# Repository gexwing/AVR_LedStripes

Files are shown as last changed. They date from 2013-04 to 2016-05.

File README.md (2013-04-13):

AVR_LedStripes
==============

Overview
-------
This Project uses an Atmega8 microcontroller to control RGB Led Stripes. The goal of this project is to have a nice modular platform with various modules to control the Color via IR Remote, Sound, or maybe other methods in the future.

src/ - The sourcecode for the Atmege, written in C.  
docs/ - documentation for hardware parts and application notes.  
eagle/ - CadSoft Eagle Schematics and Board Layout Files.  
TLSpice/ - Simulation files to test parts of the board schematics.  

Modules
-------
IRMP - Infrared Multiprotocol decoder  
SoftPWM - Software Pulse-Width-Modulation with 3 Channels via Timer Interrupt

TODO
-------
[x] Bring code upto date for v2 Board  
[] investigate gamma correction for PWM Module  
[] Add a microphone with preamp to the board for sound sampling.  
[] Add a FFT Module for anazyling sound spectrums.  
[] Add Mode for Sounds Controled Lighting  

Links
-------
Using Lookup Tables for Gamma Correction on LEDs: http://www.maximintegrated.com/app-notes/index.mvp/id/3667  
Fixed-Point FFT for Atmega: http://elm-chan.org/works/akilcd/report_e.html  
Infrared-Multiprotocol-Decoder: http://www.mikrocontroller.net/articles/IRMP  

License
-------
TBA

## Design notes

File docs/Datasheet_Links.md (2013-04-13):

FDS8884 Datasheet (N-Channel MOSFET)
------
http://www.fairchildsemi.com/ds/FD/FDS8884.pdf

TSOP1736 (IR Receiver)
------
http://www.datasheetcatalog.org/datasheets/208/301092_DS.pdf

Atmega8
------
http://www.atmel.com/devices/atmega8.aspx?tab=documents
http://www.atmel.com/Images/Atmel-2486-8-bit-AVR-microcontroller-ATmega8_L_datasheet.pdf

Application Note - AVR335: Digital Sound Recorder with tinyAVR or megaAVR and DataFlash 
------
http://www.atmel.com/Images/doc1456.pdf

Article (DE): Festkommaarithmetik
------
http://www.mikrocontroller.net/articles/Festkommaarithmetik

Article (DE): Analog-Digital-Converter
------
http://www.mikrocontroller.net/articles/AVR-GCC-Tutorial/Analoge_Ein-_und_Ausgabe

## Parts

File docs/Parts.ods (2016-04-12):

Farnell | Part Description | Cost (per unit)
1712816 | EPSON QUARZ, FA-238, 16MHZ | SFr. 0.705
2443176 | ATMEL ATMEGA328-AUR | SFr. 3.590
2407172 | ATMEL ATATMEL-ICE-BASIC DEBUGGER | SFr. 53.440
1366575 | STMICROELECTRONICS L78M05ABDT-TR TO-252-3 | SFr. 0.380
1779689 | VISHAY TSOP75236TT Infrarot-Empfänger | SFr. 1.050
2472147 | NETZANSCHLUSSBUCHSE, 5A, 24VDC | SFr. 1.900
2472151 | NETZANSCHLUSSBUCHSE, 5A, 24VDC | SFr. 1.900

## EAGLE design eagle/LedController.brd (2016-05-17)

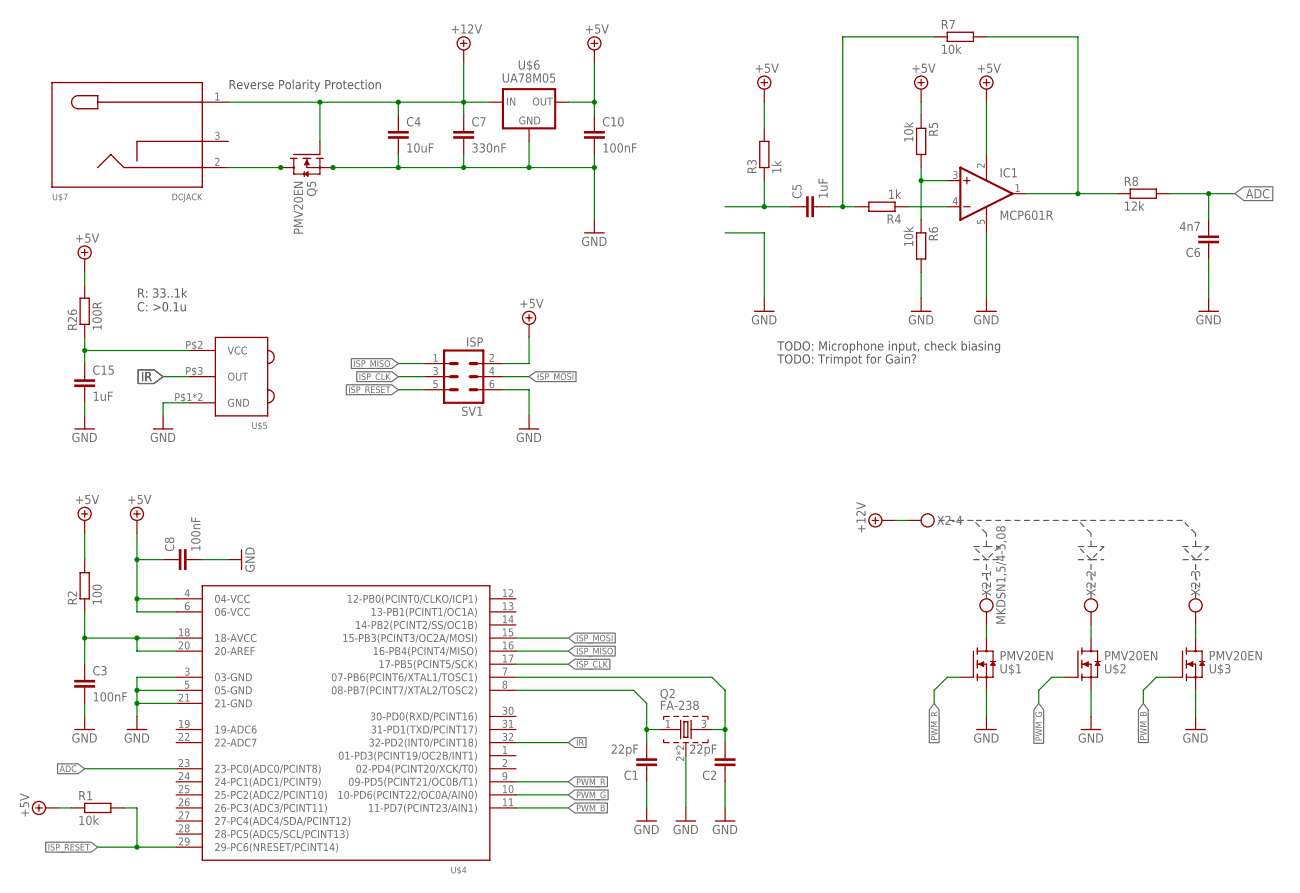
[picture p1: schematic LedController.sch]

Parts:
C1, C2: 22pF; C0805
C3, C8, C10: 100nF; C0805
C4: 10uF; C0805
C5, C15: 1uF; C0805
C6: 4n7; C0805
C7: 330nF; C0805
IC1: MCP601R; SOT23-5
Q2: FA-238
Q5: PMV20EN; SOT23
R1, R5, R6, R7: 10k; R0805
R2: 100; R0805
R3: 1k; M0805
R4: 1k; R0805
R8: 12k; R0805
R26: 100R; R0805
SV1: ISP; MA03-2
U$1, U$2, U$3: PMV20EN; SOT23
U$4: ATMEGA328; TQFP32
U$5: TSOP75236
U$6: UA78M05; SOT-223
U$7: DCJACK
X2: MKDSN1,5/4-5,08

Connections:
+5V: C8.1, C10.1, IC1.2 (V+), R1.1, R2.2, R3.2, R5.1, R26.2, SV1.2, U$4.4 (04-VCC), U$4.6 (06-VCC), U$6.3 (OUT)
+12V: C4.1, C7.1, Q5.1 (G), U$6.1 (IN), U$7.1, X2.4
ADC: C6.2, R8.2, U$4.23 (23-PC0(ADC0/PCINT8))
GND: C1.1, C2.1, C3.2, C4.2, C6.1, C7.2, C8.2, C10.2, C15.2, IC1.5 (V-), Q2.2, Q2.4 (2), Q5.2 (S), R6.2, SV1.6, U$1.2 (S), U$2.2 (S), U$3.2 (S), U$4.3 (03-GND), U$4.5 (05-GND), U$4.21 (21-GND), U$5.P$1 (GND), U$5.P$4 (GND), U$6.2 (GND), U$6.TER (GND)
IR: U$4.32 (32-PD2(INT0/PCINT18)), U$5.P$3 (OUT)
ISP_CLK: SV1.3, U$4.17 (17-PB5(PCINT5/SCK))
ISP_MISO: SV1.1, U$4.16 (16-PB4(PCINT4/MISO))
ISP_MOSI: SV1.4, U$4.15 (15-PB3(PCINT3/OC2A/MOSI))
ISP_RESET: R1.2, SV1.5, U$4.29 (29-PC6(NRESET/PCINT14))
unnamed: C5.1, R3.1
unnamed: U$1.3 (D), X2.1
unnamed: U$2.3 (D), X2.2
unnamed: U$3.3 (D), X2.3
unnamed: C3.1, R2.1, U$4.18 (18-AVCC), U$4.20 (20-AREF)
unnamed: Q5.3 (D), U$7.2
unnamed: C5.2, R4.2, R7.1
unnamed: IC1.4 (-IN), R4.1
unnamed: IC1.3 (+IN), R5.2, R6.1
unnamed: IC1.1 (OUT), R7.2, R8.1
unnamed: C1.2, Q2.1, U$4.8 (08-PB7(PCINT7/XTAL2/TOSC2))
unnamed: C2.2, Q2.3, U$4.7 (07-PB6(PCINT6/XTAL1/TOSC1))
unnamed: C15.1, R26.1, U$5.P$2 (VCC)
PWM_B: U$3.1 (G), U$4.11 (11-PD7(PCINT23/AIN1))
PWM_G: U$2.1 (G), U$4.10 (10-PD6(PCINT22/OC0A/AIN0))
PWM_R: U$1.1 (G), U$4.9 (09-PD5(PCINT21/OC0B/T1))

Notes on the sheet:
Reverse Polarity Protection
R: 33..1k C: >0.1u
TODO: Microphone input, check biasing
TODO: Trimpot for Gain?

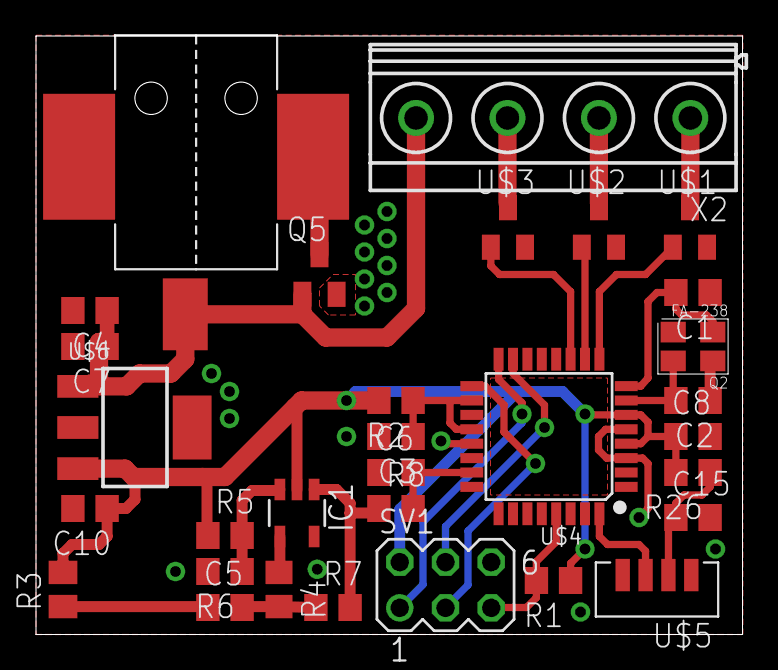
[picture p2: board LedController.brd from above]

Board: 2 copper layers, 39.2 x 33.2 mm, 31 parts (0 on the bottom side), 25 nets.

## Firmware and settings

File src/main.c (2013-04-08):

#include <avr/io.h>
#include <avr/interrupt.h>
#include "irmp/irmp.h"
#include "irmp/irmpconfig.h"
#include "softpwm.h"

#ifndef F_CPU
#error F_CPU unknown
#endif

#include "colors.h"
extern LED_Status led;

void
timer_init (void)
{
    OCR1A   =  (F_CPU / F_INTERRUPTS) - 1;      // compare value: 1/10000 of CPU frequency
    TCCR1B  = (1<<WGM12)|(1<<CS10);             // switch CTC Mode on, set prescaler to 1
    TIMSK  |= (1<<OCIE1A);                      // OCIE1A: Interrupt by timer compare
}

/*---------------------------------------------------------------------------------------------------------------------------------------------------
 * timer 1 compare handler, called every 1/10000 sec
*---------------------------------------------------------------------------------------------------------------------------------------------------
*/

ISR(TIMER1_COMPA_vect)
{
    (void) irmp_ISR();
}

/*---------------------------------------------------------------------------------------------------------------------------------------------------
 * MAIN: main routine
 *---------------------------------------------------------------------------------------------------------------------------------------------------
 */

int main (void)
{
    IRMP_DATA irmp_data;

    // Setup everything
    irmp_init();
    timer_init();
    pwm_init();

    // enable interrupts
    sei();

    // Main Loop
    for(;;)
    {
        if (!irmp_get_data(&irmp_data)) continue;

        //Repeating Commands
        if (!(irmp_data.flags&&IRMP_FLAG_REPETITION))
        {
            switch (irmp_data.command)
            {
            case 0x0B: //flash
                led.steps=0;
                if (led.mode == FLASH)
                {
                    led.mode=FIXED;
                    led.hsv.val=255;
                    led.steps=1;
                }
                else
                {
                    led.mode = FLASH;
                    led.speed = 100;
                    led.steps=1;
                }
                break;

            case 0x0F: //strobe
                led.steps=0;
                if (led.mode == STROBE)
                {
                    led.mode=FIXED;
                    led.hsv.val=255;
                }
                else
                {
                    led.mode = STROBE;
                    led.speed = 20;
                    led.hsv.sat=255;
                    led.hsv.val=255;
                }
                break;

            case 0x13: //fade
                led.steps=0;
                if (led.mode == FADE)
                {
                    led.mode=FIXED;
                    led.hsv.val=255;
                    led.speed=10;
                    led.steps=1;
                }
                else
                {
                    led.mode = FADE;
                    led.speed = 10;
                    led.hsv.sat=255;
                    led.hsv.val=255;
                    led.steps=1;
                }
                break;

            case 0x17: //smooth
                led.steps=0;
                if (led.mode == FLASH)
                {
                    led.mode=FIXED;
                    led.hsv.sat=255;
                    led.hsv.val=255;
                }
                else
                {
                    led.mode = FLASH;
                    led.speed = 0xFF;
                }
                break;
            }
        }

        //Non-Repeating Commands
        switch (irmp_data.command)
        {
            //Lightness
        case 0x00: //lighter
            if (led.hsv.val <= 245) led.hsv.val+=10;
            break;

        case 0x01: //darker
            if (led.hsv.val > 20) led.hsv.val-=10;
            break;

            //Power On/Off Maybe use idle modes?!
        case 0x02: //off
            led.hsv.val=0;
            break;

        case 0x03: //on
            led.hsv.val=255;
            break;

            //Predefined Colors
        case 0x04: //R
            led.mode=FIXED;
            sethsv(0,255,255);
            break;

        case 0x05: //G
            led.mode=FIXED;
            sethsv(85,255,255);
            break;

        case 0x06: //B
            led.mode=FIXED;
            sethsv(170,255,255);
            break;

        case 0x07: //W
            led.mode=FIXED;
            sethsv(0,0,255);
            break;

        case 0x08:
            led.mode=FIXED;
            sethsv(42,255,255);
            break;

        case 0x09:
            led.mode=FIXED;
            sethsv(127,255,255);
            break;

        case 0x0A:
            led.mode=FIXED;
            sethsv(212,255,255);
            break;

        case 0x0C: // Speed+
            if (led.speed > 1) --led.speed;
            break;

        case 0x0D:
            led.hsv.hue+=2;
            break;

        case 0x0E:
            if (led.hsv.sat<250) led.hsv.sat+=5;
            break;

        case 0x10: // Speed-
            if (led.speed < 255) ++led.speed;
            break;

        case 0x11: //hue-
            led.hsv.hue-=2;
            break;

        case 0x12:
            if (led.hsv.sat>5) led.hsv.sat-=5;
            break;

        case 0x14:
            break;

        case 0x15:
            break;

        case 0x16:
            break;

        }
    }
}

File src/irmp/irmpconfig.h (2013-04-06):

/*---------------------------------------------------------------------------------------------------------------------------------------------------
 * irmpconfig.h
 *
 * Copyright (c) 2010 Frank Meyer - frank(at)fli4l.de
 *
 * $Id: irmpconfig.h,v 1.34 2010/06/26 18:11:08 fm Exp $
 *
 * ATMEGA88 @ 8 MHz
 *
 * This program is free software; you can redistribute it and/or modify
 * it under the terms of the GNU General Public License as published by
 * the Free Software Foundation; either version 2 of the License, or
 * (at your option) any later version.
 *---------------------------------------------------------------------------------------------------------------------------------------------------
 */

#ifndef _IRMPCONFIG_H_
#define _IRMPCONFIG_H_

/*---------------------------------------------------------------------------------------------------------------------------------------------------
 * Change F_INTERRUPTS if you change the number of interrupts per second,
 * Normally, F_INTERRUPTS should be in the range from 10000 to 15000.
 * A value above 15000 costs additional program space, absolut maximum value is 20000.
 *---------------------------------------------------------------------------------------------------------------------------------------------------
 */
#ifndef F_INTERRUPTS
#define F_INTERRUPTS                            10000   // interrupts per second, min: 10000, max: 15000
#endif

/*---------------------------------------------------------------------------------------------------------------------------------------------------
 * Change settings from 1 to 0 if you want to disable one or more decoders.
 * This saves program space.
 *
 * 1 enable  decoder
 * 0 disable decoder
 *
 * The standard decoders are enabled per default.
 * Some less common protocols are disabled here, you need to enable them manually.
 *
 * If you want to use FDC or RCCAR simultaneous with RC5 protocol, additional program space is required.
 * If you don't need RC5 when using FDC/RCCAR, you should disable RC5.
 *---------------------------------------------------------------------------------------------------------------------------------------------------
 */

//      Protocol                                Enable  Remarks                 F_INTERRUPTS        Program Space
#define IRMP_SUPPORT_SIRCS_PROTOCOL             1       // Sony SIRCS           >= 10000                 ~100 bytes
#define IRMP_SUPPORT_NEC_PROTOCOL               1       // NEC + APPLE          >= 10000                 ~250 bytes
#define IRMP_SUPPORT_SAMSUNG_PROTOCOL           0       // Samsung + Samsung32  >= 10000                 ~250 bytes
#define IRMP_SUPPORT_MATSUSHITA_PROTOCOL        0       // Matsushita           >= 10000                  ~50 bytes
#define IRMP_SUPPORT_KASEIKYO_PROTOCOL          0       // support Kaseikyo     >= 10000                  ~50 bytes
#define IRMP_SUPPORT_DENON_PROTOCOL             0       // support DENON        >= 10000                 ~250 bytes
#define IRMP_SUPPORT_RC5_PROTOCOL               0       // RC5                  >= 10000                 ~250 bytes
#define IRMP_SUPPORT_RC6_PROTOCOL               0       // RC6                  >= 10000                 ~200 bytes

#define IRMP_SUPPORT_GRUNDIG_PROTOCOL           0       // Grundig              >= 10000                 ~150 bytes
#define IRMP_SUPPORT_NOKIA_PROTOCOL             0       // Nokia                >= 10000                 ~150 bytes
#define IRMP_SUPPORT_NUBERT_PROTOCOL            0       // NUBERT               >= 10000                  ~50 bytes
#define IRMP_SUPPORT_BANG_OLUFSEN_PROTOCOL      0       // Bang & Olufsen       >= 10000                 ~200 bytes
#define IRMP_SUPPORT_FDC_PROTOCOL               0       // FDC3402 keyboard     >= 10000 (better 15000)   ~50 bytes (~400 in combination with RC5)
#define IRMP_SUPPORT_RCCAR_PROTOCOL             0       // RC Car               >= 10000 (better 15000)  ~150 bytes (~500 in combination with RC5)
#define IRMP_SUPPORT_SIEMENS_PROTOCOL           0       // Siemens Gigaset      >= 15000                 ~150 bytes
#define IRMP_SUPPORT_RECS80_PROTOCOL            0       // RECS80               >= 20000                  ~50 bytes
#define IRMP_SUPPORT_RECS80EXT_PROTOCOL         0       // RECS80EXT            >= 20000                  ~50 bytes

/*---------------------------------------------------------------------------------------------------------------------------------------------------
 * Change hardware pin here:
 *---------------------------------------------------------------------------------------------------------------------------------------------------
 */
#ifdef PIC_CCS_COMPILER                                 // PIC CCS Compiler:

#define IRMP_PIN                                PIN_B4  // use PB4 as IR input on PIC

#else                                                   // AVR:
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

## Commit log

2013-04-07 Adding Eagle files
    [LedController.brd, LedController.sch]
2013-04-08 Cleanup for new Eagle version
    [LedController.brd, LedController.sch]
2013-04-09 Add reverse polarity protection
    [LedController.brd, LedController.sch]
2013-04-09 Changing Signal Names, split up into individual parts in schematic
    [LedController.brd, LedController.sch]
2013-04-13 add preamp stage for microphone
    [LedController.brd, LedController.sch]
2013-04-30 new preamp circuit
2016-04-11 Replace atmega8 (DIP) with atmega328 (TQFP), start of redesign
    [LedController.brd, LedController.sch, Parts.ods]
2016-04-11 Change IR Receiver module to SMD variant
    [LedController.brd, LedController.sch, Parts.ods]
2016-04-11 Change voltage regulator to DPAK variant
    [LedController.brd, LedController.sch]
2016-04-12 Add DC Barrel Jack
    [LedController.brd, LedController.sch, Parts.ods]
2016-04-12 Cosmetic Changes in Board Schematic
    [LedController.brd, LedController.sch]
2016-04-12 Change crystal to SMD type
    [LedController.brd, LedController.sch]
2016-05-12 Change ISP Connector, layout most things
    [LedController.brd, LedController.sch]
2016-05-17 More relayouting, Framed schematic
    [LedController.brd, LedController.sch]
